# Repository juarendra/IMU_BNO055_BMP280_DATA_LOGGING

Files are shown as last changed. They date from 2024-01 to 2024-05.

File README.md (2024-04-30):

# IMU_BNO055_BMP280_DATA_LOGGING

## Spesification
- ESP32 WROOM
- USB TYPE C
- FT231 as USB Proggrammer
- BNO055
- BMP280
- OLED DISPLAY
- I2C expander for Button
- Modul charger tp4056 for Charger Lipo Batt
- Switch On OFF
- SD Card as save Data Loging

## Preview Hardware
<p align="center">

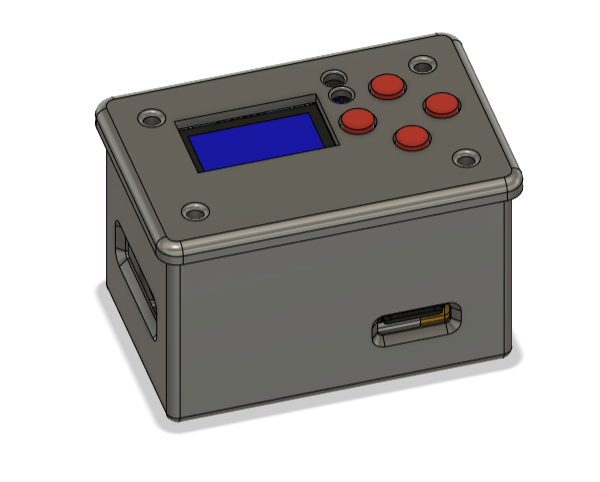
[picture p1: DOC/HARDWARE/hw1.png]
  
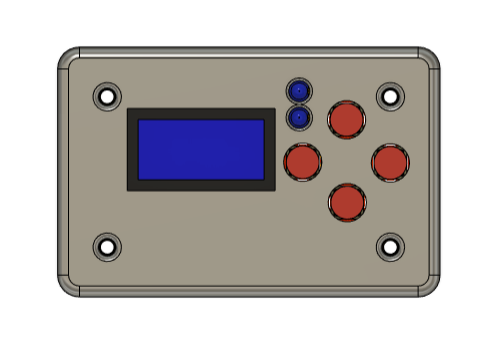
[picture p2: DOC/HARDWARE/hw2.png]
  
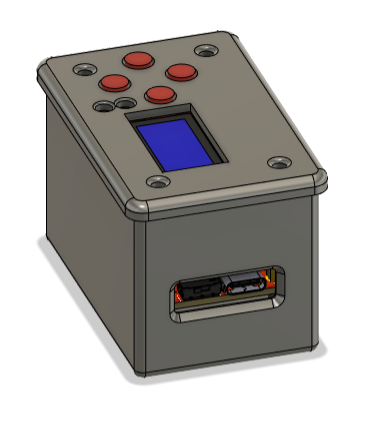
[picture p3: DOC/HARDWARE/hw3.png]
  
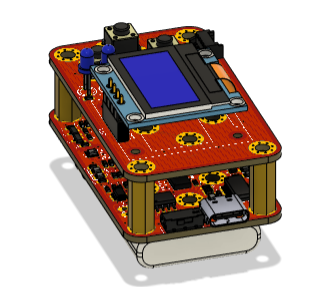
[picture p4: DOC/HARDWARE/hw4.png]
  
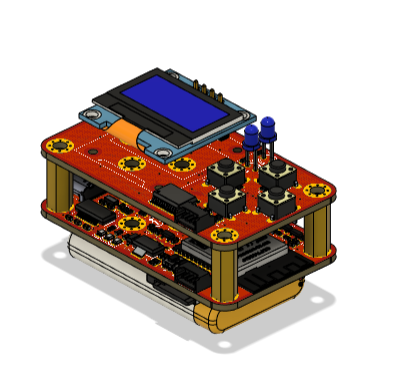
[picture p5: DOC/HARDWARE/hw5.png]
  
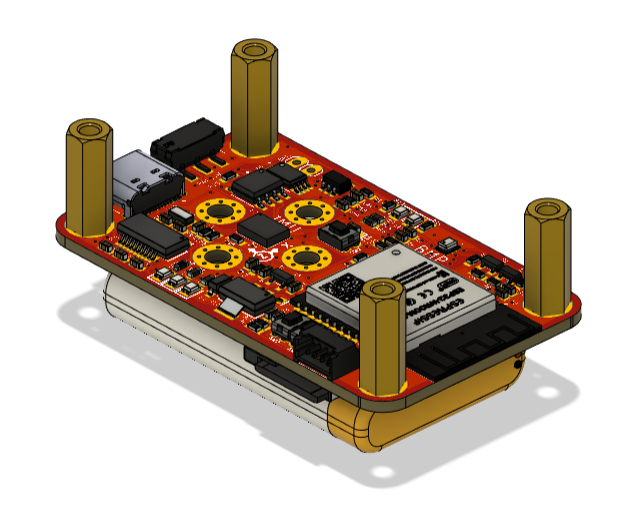
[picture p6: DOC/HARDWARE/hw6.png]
  
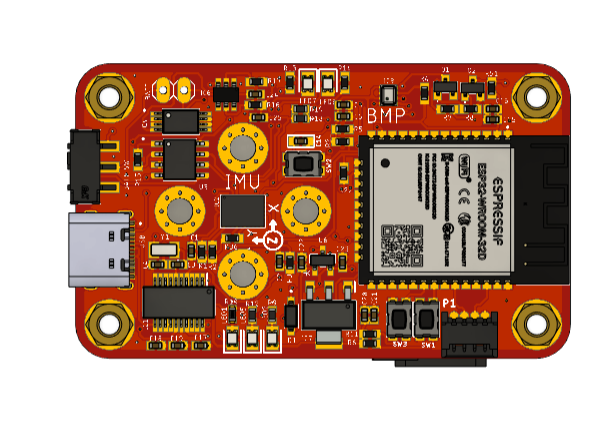
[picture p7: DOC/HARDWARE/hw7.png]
  
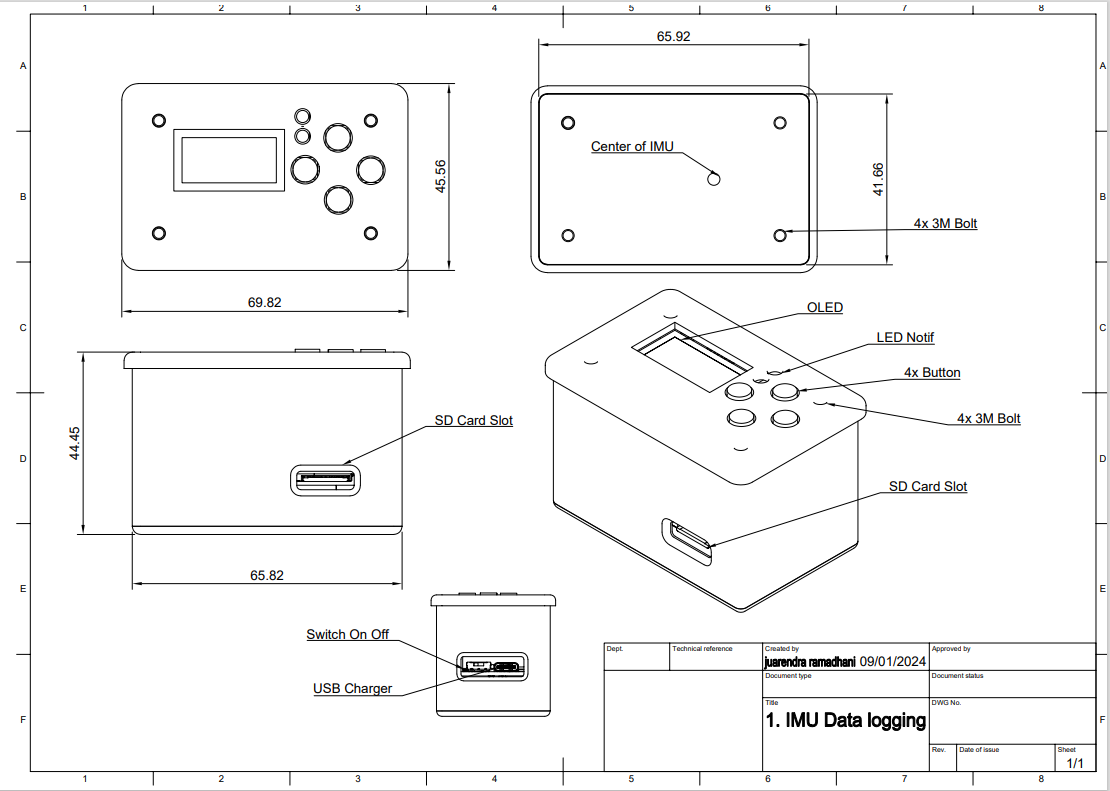
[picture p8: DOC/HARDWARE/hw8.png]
  

</p>

## USAGE 
- First you need to order or print the PCB based the gerber file on [this folder](https://github.com/juarendra/IMU_BNO055_BMP280_DATA_LOGGING/tree/main/GERBER)
- there are two PCB File, first is the MAIN Board and second is the UI with OLED and Button
- you need to print all PCB file to your favorite Manufacture PCB.
- then you can order all component based the BOM LIST file on [this folder](https://github.com/juarendra/IMU_BNO055_BMP280_DATA_LOGGING/tree/main/BOM).
- after All PCBs and All Component are receive, you can start the assembly 
- Then Print Case on [this Folder](https://github.com/juarendra/IMU_BNO055_BMP280_DATA_LOGGING/tree/main/CASE) with your 3D print

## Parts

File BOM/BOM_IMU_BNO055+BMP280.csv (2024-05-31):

Qty | Value | Device | Package | Parts | Description | AVAILABILITY | CHECK_PRICES | DESCRIPTION | DIGIKEY_PARTNUMBER | DIGIKEY_PRICE-STOCK | HEIGHT | LCSC_PART_NUMBER | LCSC_PRICE-STOCK | MANUFACTURER_NAME | MANUFACTURER_PART_NUMBER | MF | MOUSER_PART_NUMBER | MOUSER_PRICE-STOCK | MP | PACKAGE | PART_NUMBER | POPULARITY | PRICE | PURCHASE-URL | SNAPEDA_LINK | VALUE
1 |  | PINHD-1X2 | 1X02 | BATT | PIN HEADER |  |  |  |  |  |  |  |  |  |  |  |  |  |  |  |  | 98
7 | 0 | RC0603FR-070RL | RESC1608X55N | R29, R30, R31, R32, R33, R34, R35 | YAGEO - RC0603FR-070RL - Zero Ohm Resistor, Jumper, 0603 [1608 Metric], Thick Film, 100 mW, 1 A, Surface Mount Device |  |  | YAGEO - RC0603FR-070RL - Zero Ohm Resistor, Jumper, 0603 [1608 Metric], Thick Film, 100 mW, 1 A, Surface Mount Device |  |  | 0.55mm |  |  | YAGEO | RC0603FR-070RL |  | 603-RC0603FR-070RL | https://www.mouser.co.uk/ProductDetail/YAGEO/RC0603FR-070RL?qs=0yPvnVz5%2FmpDQv43TwvCfw%3D%3D
1 | 1.2k | ESR03EZPJ102 | RESC1608X55N | R15 | Thick Film Resistors - SMD 0603 1Kohm 5% Anti Surge AEC-Q200 |  |  | Thick Film Resistors - SMD 0603 1Kohm 5% Anti Surge AEC-Q200 | RHM1.0KDCT-ND | https://www.digikey.com/product-detail/en/rohm-semiconductor/ESR03EZPJ102/RHM1-0KDCT-ND/1762924 | 0.55mm |  |  | ROHM Semiconductor | ESR03EZPJ102 |  | 755-ESR03EZPJ102 | https://www.mouser.co.uk/ProductDetail/ROHM-Semiconductor/ESR03EZPJ102?qs=DyUWGjl%252BcVvjMuV%252BzioV7Q%3D%3D |  |  |  |  |  |  |  | 1k
1 | 100 | ESR03EZPJ102 | RESC1608X55N | R16 | Thick Film Resistors - SMD 0603 1Kohm 5% Anti Surge AEC-Q200 |  |  | Thick Film Resistors - SMD 0603 1Kohm 5% Anti Surge AEC-Q200 | RHM1.0KDCT-ND | https://www.digikey.com/product-detail/en/rohm-semiconductor/ESR03EZPJ102/RHM1-0KDCT-ND/1762924 | 0.55mm |  |  | ROHM Semiconductor | ESR03EZPJ102 |  | 755-ESR03EZPJ102 | https://www.mouser.co.uk/ProductDetail/ROHM-Semiconductor/ESR03EZPJ102?qs=DyUWGjl%252BcVvjMuV%252BzioV7Q%3D%3D |  |  |  |  |  |  |  | 1k
13 | 100nf | 885012206071 | CAPC1608X87N | C1, C2, C5, C6, C7, C8, C15, C17, C18, C19, C23, C24, C25 | Wurth Elektronik 0603 WCAP-CSGP 100nF Ceramic Multilayer Capacitor, 25 V dc, +125C, X7R Dielectric, +/-10% |  |  | Wurth Elektronik 0603 WCAP-CSGP 100nF Ceramic Multilayer Capacitor, 25 V dc, +125C, X7R Dielectric, +/-10% | 732-7989-1-ND | https://www.digikey.com/product-detail/en/w%C3%BCrth-elektronik/885012206071/732-7989-1-ND/5454616 | 0.87mm |  |  | Wurth Elektronik | 885012206071 |  | 710-885012206071 | https://www.mouser.co.uk/ProductDetail/Wurth-Elektronik/885012206071?qs=0KOYDY2FL2%2FEBQkuHgvarg%3D%3D |  |  |  |  |  |  |  | 100nf
20 | 10k | ESR03EZPJ103 | RESC1608X55N | R1, R2, R3, R4, R5, R6, R7, R8, R11, R20, R21, R22, R23, R24, R25, R26, R27, R28, R36, R51 | Thick Film Resistors - SMD 0603 10Kohm 5% Anti Surge AEC-Q200 |  |  | Thick Film Resistors - SMD 0603 10Kohm 5% Anti Surge AEC-Q200 | RHM10KDCT-ND | https://www.digikey.com/product-detail/en/rohm-semiconductor/ESR03EZPJ103/RHM10KDCT-ND/1762925 | 0.55mm |  |  | ROHM Semiconductor | ESR03EZPJ103 |  | 755-ESR03EZPJ103 | https://www.mouser.com/Search/Refine.aspx?Keyword=755-ESR03EZPJ103 |  |  |  |  |  |  |  | 10k
2 | 10nf | 885012206089 | CAPC1608X87N | C16, C21 | Wurth Elektronik 0603 WCAP-CSGP 10nF Ceramic Multilayer Capacitor, 50 V dc, +125C, X7R Dielectric, +/-10% |  |  | Wurth Elektronik 0603 WCAP-CSGP 10nF Ceramic Multilayer Capacitor, 50 V dc, +125C, X7R Dielectric, +/-10% | 732-8007-1-ND | https://www.digikey.com/product-detail/en/w%C3%BCrth-elektronik/885012206089/732-8007-1-ND/5454634 | 0.87mm |  |  | Wurth Elektronik | 885012206089 |  | 710-885012206089 | https://www.mouser.co.uk/ProductDetail/Wurth-Elektronik/885012206089?qs=0KOYDY2FL28GvSbKh319Tw%3D%3D |  |  |  |  |  |  |  | 10nf
1 | 1N5819HW-7 | 1N5819HW-7 | SOD3715X145N | D1 | 1N5819HW Series 40 V 1 A Surface Mount Schottky Barrier Rectifier - SOD-123 Check availability | In Stock | https://www.snapeda.com/parts/1N5819HW-7/Diodes+Inc./view-part/?ref=eda | Diode Schottky 40 V 1A Surface Mount SOD-123 |  |  |  |  |  |  |  | Diodes Inc. |  |  | 1N5819HW-7 | SOD-123 Fairchild Semiconductor |  |  | None | https://www.snapeda.com/api/url_track_click_mouser/?unipart_id=51510&manufacturer=Diodes Inc.&part_name=1N5819HW-7&search_term=1n5819 | https://www.snapeda.com/parts/1N5819HW-7/Diodes+Inc./view-part/?ref=snap
3 | 1k | ESR03EZPJ102 | RESC1608X55N | R13, R14, R17 | Thick Film Resistors - SMD 0603 1Kohm 5% Anti Surge AEC-Q200 |  |  | Thick Film Resistors - SMD 0603 1Kohm 5% Anti Surge AEC-Q200 | RHM1.0KDCT-ND | https://www.digikey.com/product-detail/en/rohm-semiconductor/ESR03EZPJ102/RHM1-0KDCT-ND/1762924 | 0.55mm |  |  | ROHM Semiconductor | ESR03EZPJ102 |  | 755-ESR03EZPJ102 | https://www.mouser.co.uk/ProductDetail/ROHM-Semiconductor/ESR03EZPJ102?qs=DyUWGjl%252BcVvjMuV%252BzioV7Q%3D%3D |  |  |  |  |  |  |  | 1k
1 | 1uF | CAP_CERAMIC0603 | 0603 | C14 | Ceramic Capacitors
2 | 1uf | 885012206071 | CAPC1608X87N | C20, C22 | Wurth Elektronik 0603 WCAP-CSGP 100nF Ceramic Multilayer Capacitor, 25 V dc, +125C, X7R Dielectric, +/-10% |  |  | Wurth Elektronik 0603 WCAP-CSGP 100nF Ceramic Multilayer Capacitor, 25 V dc, +125C, X7R Dielectric, +/-10% | 732-7989-1-ND | https://www.digikey.com/product-detail/en/w%C3%BCrth-elektronik/885012206071/732-7989-1-ND/5454616 | 0.87mm |  |  | Wurth Elektronik | 885012206071 |  | 710-885012206071 | https://www.mouser.co.uk/ProductDetail/Wurth-Elektronik/885012206071?qs=0KOYDY2FL2%2FEBQkuHgvarg%3D%3D |  |  |  |  |  |  |  | 100nf
2 | 22pf | 885012006004 | CAPC1608X87N | C3, C4 | Multilayer Ceramic Chip Capacitor WCAP-CSGP Series 0603 22pF NP00603220J010DFCT10000 |  |  | Multilayer Ceramic Chip Capacitor WCAP-CSGP Series 0603 22pF NP00603220J010DFCT10000 |  |  | 0.87mm |  |  | Wurth Elektronik | 885012006004 |  | 710-885012006004 | https://www.mouser.co.uk/ProductDetail/Wurth-Elektronik/885012006004?qs=0KOYDY2FL2%252BKoFRSQTlJcA%3D%3D |  |  |  |  |  |  |  | 22pf
3 | 330 | ERJ-H3EF3300V | ERJH3 | R9, R10, R12 | Power Rating 0.125W,Resistance 330 Ohm,LxW(EIA) 1.6 x 0.8 (EIA:0603) mm |  |  | Power Rating 0.125W,Resistance 330 Ohm,LxW(EIA) 1.6 x 0.8 (EIA:0603) mm |  |  | mm |  |  | Panasonic | ERJ-H3EF3300V |  | 667-ERJ-H3EF3300V | https://www.mouser.co.uk/ProductDetail/Panasonic/ERJ-H3EF3300V?qs=eP2BKZSCXI61roRLPi8W7w%3D%3D |  |  |  |  |  |  |  | 330
8 | 3MM_HOLE | 3MM_HOLE | 3MM_HOLE | H1, H2, H3, H4, H5, H6, H7, H8 | Cool looking 3mm hole with ground connection
1 | 40k2 | ERJ-S03F4022V | RESC1608X55N | R37 | Thick Film Resistors - SMD 0603 40.2Kohms 1% Anti-Sulfur |  |  | Thick Film Resistors - SMD 0603 40.2Kohms 1% Anti-Sulfur |  |  | 0.55mm |  |  | Panasonic | ERJ-S03F4022V |  | 667-ERJ-S03F4022V | https://www.mouser.com/Search/Refine.aspx?Keyword=667-ERJ-S03F4022V
2 | 47k | ERJ-H3EF3300V | ERJH3 | R18, R19 | Power Rating 0.125W,Resistance 330 Ohm,LxW(EIA) 1.6 x 0.8 (EIA:0603) mm |  |  | Power Rating 0.125W,Resistance 330 Ohm,LxW(EIA) 1.6 x 0.8 (EIA:0603) mm |  |  | mm |  |  | Panasonic | ERJ-H3EF3300V |  | 667-ERJ-H3EF3300V | https://www.mouser.co.uk/ProductDetail/Panasonic/ERJ-H3EF3300V?qs=eP2BKZSCXI61roRLPi8W7w%3D%3D |  |  |  |  |  |  |  | 330
1 | 53048-0410 | 53048-0410 | 53048-0410 | P1 | HEADER Check availability | In Stock | https://www.snapeda.com/parts/53048-0410/Molex/view-part/?ref=eda | 4 way through board PCB 90deg header | Molex Incorporated 53048-0410 |  |  |  |  |  |  |  | Molex |  |  | 53048-0410 | None |  |  | None |  | https://www.snapeda.com/parts/53048-0410/Molex/view-part/?ref=snap
1 | BMP280 | BMP280 | 8-PIN-METAL-LID-LGA | IC3 | Digital Pressure Sensor |  |  | Digital Pressure Sensor |  |  | mm |  |  | BOSCH | bmp280 |  | 262-BMP280 | https://www.mouser.co.uk/ProductDetail/Bosch-Sensortec/BMP280?qs=QhAb4EtQfbUP9Z%252BCHM3Wyg%3D%3D
1 | BN055 | 1658_BNO055 | LGA-28_3.80X5.20/0.5 | IC2 | BN055 Intelligent 9-axis absolute orientation sensor |  |  |  |  |  |  |  |  |  |  |  |  |  |  |  | BNO055 |  |  |  |  | BN055
1 | DW01A | DW01A | SOT23-6 | IC6 | Check availability | Not in stock | https://www.snapeda.com/parts/DW01A/Fortune+Semiconductor/view-part/?ref=eda | One Cell Lithium-ion/Polymer Battery Protection IC |  |  |  |  |  |  |  | Fortune Semiconductor |  |  | DW01A | SOT-23-6 Fortune Semiconductor |  |  | None |  | https://www.snapeda.com/parts/DW01A/Fortune+Semiconductor/view-part/?ref=snap
1 | ECS-.327-12.5-34B | ECS-.327-12.5-34B | ECX-31B | Y1 | Crystals 32.768KHz 20ppm 12.5pF -40C +85C |  |  | Crystals 32.768KHz 20ppm 12.5pF -40C +85C |  |  | mm |  |  | ECS | ECS-.327-12.5-34B |  | 520-ECS-327-12.5-34B | https://www.mouser.co.uk/ProductDetail/ECS/ECS-.327-12.5-34B?qs=muFWWzTLGEJ4ncukpyY8Bw%3D%3D
1 | ESP32-WROOM-32D | ESP32-WROOM-32D | MODULE_ESP32-WROOM-32D | U4 | Bluetooth, WiFi 802.11b/g/n, Bluetooth v4.2 + EDR, Class 1, 2 and 3 Transceiver Module 2.4GHz ~ 2.5GHz Integrated, Trace Surface Mount Check availability | In Stock |  | Bluetooth, WiFi 802.11b/g/n, Bluetooth v4.2 +EDR, Class 1, 2 and 3 Transceiver Module 2.4GHz ~ 2.5GHz Integrated |  |  |  |  |  |  |  | Espressif Systems |  |  | ESP32-WROOM-32D | Module Espressif Systems |  |  | None | https://pricing.snapeda.com/search/part/ESP32-WROOM-32D/?ref=eda
1 | FS8205A | FS8205A | SOP65P640X120-8N | Q4 | N/A Check availability | Not in stock | https://www.snapeda.com/parts/FS8205A/Fortune+Semiconductor/view-part/?ref=eda |  |  |  |  |  |  |  |  | Fortune Semiconductor |  |  | FS8205A | Package |  |  | None |  | https://www.snapeda.com/parts/FS8205A/Fortune+Semiconductor/view-part/?ref=snap
1 | FT231XS-R | FT231XS-R | SOP64P599X175-20N | IC1 | FTDI Chip FT231XS-R, Interface RS232, RS422, RS485, SIE, UART 3MBd, 5 V, 20-pin, SSOP |  |  | FTDI Chip FT231XS-R, Interface RS232, RS422, RS485, SIE, UART 3MBd, 5 V, 20-pin, SSOP |  |  | 1.753mm |  |  | FTDI Chip | FT231XS-R |  | 895-FT231XS-R | https://www.mouser.co.uk/ProductDetail/FTDI/FT231XS-R?qs=Gp1Yz1mis3WduRPsgrTbtg%3D%3D
5 | Green | 150080BS75000 | LEDC2012X80N | LED1, LED2, LED5, LED6, LED7 | LED,Wurth Elektronik,150080BS75000 Wurth Elektronik 150080BS75000, WL-SMCW Series Blue LED, 470 nm 2012 (0805) Clear, Rectangle Lens SMD package |  |  | LED,Wurth Elektronik,150080BS75000 Wurth Elektronik 150080BS75000, WL-SMCW Series Blue LED, 470 nm 2012 (0805) Clear, Rectangle Lens SMD package |  |  | 0.8mm |  |  | Wurth Elektronik | 150080BS75000 |  | 710-150080BS75000 | https://www.mouser.co.uk/ProductDetail/Wurth-Elektronik/150080BS75000?qs=2kOmHSv6VfT2tBo3UPVqAQ%3D%3D |  |  |  |  |  |  |  | Green
1 | JS102011SAQN | JS102011SAQN | SW_JS102011SAQN | BATT_SW | <b> | In Stock | https://www.snapeda.com/parts/JS102011SAQN/C%2526K/view-part/?ref=eda | Slide Switch SPDT Surface Mount, Right Angle |  |  |  |  |  |  |  | C&K |  |  | JS102011SAQN | None |  |  | None | https://pricing.snapeda.com/search?q=JS102011SAQN&ref=eda | https://www.snapeda.com/parts/JS102011SAQN/C%2526K/view-part/?ref=snap
3 | KMR2 | SWITCH_TACT_SMT4.6X2.8 | BTN_KMR2_4.6X2.8 | SW1, SW2, SW3 | SMT Tact Switches
1 | M3406-ADJ | M3406-ADJ | SOT95P280X100-5N | IC4 | Step-down type SOT-23-5 DC-DC Converters ROHS |  |  | Step-down type SOT-23-5 DC-DC Converters ROHS |  |  | 1mm | C83224 | https://www.lcsc.com/product-detail/DC-DC-Converters_XI-AN-Aerosemi-Tech-M3406-ADJ_C83224.html | XI'AN Aerosemi Tech | M3406-ADJ
1 | MICROSD-PUSH-OUT | MICROSD-PUSH-OUT | MICROSD-PUSH-OUT | U$3 | T-Flash Push-Out Micro SD Card Reader
1 | MLF2012A2R2KT000 | MLF2012A2R2KT000 | INDC2012X105N | L1 | 2.2 H Shielded Multilayer Inductor 50 mA 500mOhm Max 0805 (2012 Metric) |  |  | 2.2 H Shielded Multilayer Inductor 50 mA 500mOhm Max 0805 (2012 Metric) |  |  | 1.05mm |  |  | TDK | MLF2012A2R2KT000 |  | 810-MLF2012A2R2KT000 | https://www.mouser.co.uk/ProductDetail/TDK/MLF2012A2R2KT000?qs=pLY5GE0xrmL3Y2Jw%2FEGjFg%3D%3D
2 | MMBT3904-TP | MMBT3904-TP | SI2305TP | Q1, Q2 | Bipolar Transistors - BJT 40V |  |  | Bipolar Transistors - BJT 40V |  |  | mm |  |  | Micro Commercial Components (MCC) | MMBT3904-TP |  | 833-MMBT3904-TP | https://www.mouser.co.uk/ProductDetail/Micro-Commercial-Components-MCC/MMBT3904-TP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
1 | SI2301BDS-T1-E3 | SI2301BDS-T1-E3 | SOT95P237X112-3N | U6 | MOSFET Check availability | In Stock | https://www.snapeda.com/parts/SI2301BDS-T1-E3/Vishay+Siliconix/view-part/?ref=eda | MOSFET,P-Ch,VDSS -20V,RDS(ON) 0.08Ohm,ID -2.2A,TO-236 (SOT-23),PD 0.7W,VGS +/-8V | Siliconix / Vishay SI2301BDS-T1-E3 |  |  |  |  |  |  |  | Vishay |  |  | SI2301BDS-T1-E3 | SOT-23-3 Vishay Siliconix |  |  | None | https://www.snapeda.com/api/url_track_click_mouser/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 | https://www.snapeda.com/parts/SI2301BDS-T1-E3/Vishay+Siliconix/view-part/?ref=snap
1 | TP4056 | TP4056 | SOP127P600X175-9N | U3 | Complete single cell Li-Ion battery with a constant current / constant voltage linear charger Check availability | Not in stock | https://www.snapeda.com/parts/TP4056/NanJing+Top+Power+ASIC+Corp./view-part/?ref=eda | Complete single cell Li-Ion battery with a constant current / constant voltage linear charger |  |  |  |  |  |  |  | NanJing Top Power ASIC Corp. |  |  | TP4056 | Package |  |  | None |  | https://www.snapeda.com/parts/TP4056/NanJing+Top+Power+ASIC+Corp./view-part/?ref=snap
1 | TYPE-C-31-M-12 | TYPE-C-31-M-12 | HRO_TYPE-C-31-M-12 | USB | Check availability | Not in stock | https://www.snapeda.com/parts/TYPE-C-31-M-12/HRO+Electronics+Co.%252C+Ltd./view-part/?ref=eda | USB Connectors 24 Receptacle 1 8.94*7.3mm RoHS |  |  |  |  |  |  |  | HRO Electronics Co., Ltd. |  |  | TYPE-C-31-M-12 | Package |  |  | None |  | https://www.snapeda.com/parts/TYPE-C-31-M-12/HRO+Electronics+Co.%252C+Ltd./view-part/?ref=snap

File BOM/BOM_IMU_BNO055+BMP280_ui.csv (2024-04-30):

Qty | Value | Device | Package | Parts | Description | AVAILABILITY | CHECK_PRICES | DESCRIPTION | DIGIKEY_PARTNUMBER | DIGIKEY_PRICE-STOCK | HEIGHT | MANUFACTURER_NAME | MANUFACTURER_PART_NUMBER | MF | MOUSER_PART_NUMBER | MOUSER_PRICE-STOCK | MP | MPN | OC_FARNELL | OC_NEWARK | PACKAGE | POPULARITY | PRICE | SNAPEDA_LINK | VALUE
4 |  | 10-XX | B3F-10XX | S1, S2, S3, S4 | OMRON SWITCH |  |  |  |  |  |  |  |  |  |  |  |  | B3F-1000 | 176432 | 36M3542 |  | 72
2 |  | LED3MM | LED3MM | LED1, LED2 | LED |  |  |  |  |  |  |  |  |  |  |  |  |  |  |  |  | 97
2 | 100nf | 885012206071 | CAPC1608X87N | C1, C2 | Wurth Elektronik 0603 WCAP-CSGP 100nF Ceramic Multilayer Capacitor, 25 V dc, +125C, X7R Dielectric, +/-10% |  |  | Wurth Elektronik 0603 WCAP-CSGP 100nF Ceramic Multilayer Capacitor, 25 V dc, +125C, X7R Dielectric, +/-10% | 732-7989-1-ND | https://www.digikey.com/product-detail/en/w%C3%BCrth-elektronik/885012206071/732-7989-1-ND/5454616 | 0.87mm | Wurth Elektronik | 885012206071 |  | 710-885012206071 | https://www.mouser.co.uk/ProductDetail/Wurth-Elektronik/885012206071?qs=0KOYDY2FL2%2FEBQkuHgvarg%3D%3D |  |  |  |  |  |  |  |  | 100nf
6 | 10k | ESR03EZPJ103 | RESC1608X55N | R1, R2, R3, R4, R5, R6 | Thick Film Resistors - SMD 0603 10Kohm 5% Anti Surge AEC-Q200 |  |  | Thick Film Resistors - SMD 0603 10Kohm 5% Anti Surge AEC-Q200 | RHM10KDCT-ND | https://www.digikey.com/product-detail/en/rohm-semiconductor/ESR03EZPJ103/RHM10KDCT-ND/1762925 | 0.55mm | ROHM Semiconductor | ESR03EZPJ103 |  | 755-ESR03EZPJ103 | https://www.mouser.com/Search/Refine.aspx?Keyword=755-ESR03EZPJ103 |  |  |  |  |  |  |  |  | 10k
2 | 1k | ESR03EZPJ102 | RESC1608X55N | R7, R8 | Thick Film Resistors - SMD 0603 1Kohm 5% Anti Surge AEC-Q200 |  |  | Thick Film Resistors - SMD 0603 1Kohm 5% Anti Surge AEC-Q200 | RHM1.0KDCT-ND | https://www.digikey.com/product-detail/en/rohm-semiconductor/ESR03EZPJ102/RHM1-0KDCT-ND/1762924 | 0.55mm | ROHM Semiconductor | ESR03EZPJ102 |  | 755-ESR03EZPJ102 | https://www.mouser.co.uk/ProductDetail/ROHM-Semiconductor/ESR03EZPJ102?qs=DyUWGjl%252BcVvjMuV%252BzioV7Q%3D%3D |  |  |  |  |  |  |  |  | 1k
8 | 3MM_HOLE | 3MM_HOLE | 3MM_HOLE | H1, H2, H3, H4, H5, H6, H7, H8 | Cool looking 3mm hole with ground connection
1 | 53048-0410 | 53048-0410 | 53048-0410 | P1 | HEADER Check availability | In Stock | https://www.snapeda.com/parts/53048-0410/Molex/view-part/?ref=eda | 4 way through board PCB 90deg header | Molex Incorporated 53048-0410 |  |  |  |  |  | Molex |  |  | 53048-0410 |  |  |  | None |  | None | https://www.snapeda.com/parts/53048-0410/Molex/view-part/?ref=snap
1 | DISPLAY-OLED-128X64-I2C | DISPLAY-OLED-128X64-I2C | DISPLAY-OLED-128X64-I2C | U$1 | 128x64 Dot Matrix OLED Module based on SSD1306 chip
1 | PCF8575TS_1,118 | PCF8575TS_1,118 | SOP65P775X200-24N | IC1 | Interface - I/O Expanders |  |  | Interface - I/O Expanders |  |  | 2mm | NXP | PCF8575TS/1,118 |  | 771-PCF8575TSDB-T | https://www.mouser.co.uk/ProductDetail/NXP-Semiconductors/PCF8575TS-1118?qs=LOCUfHb8d9vMl26vh33NWQ%3D%3D

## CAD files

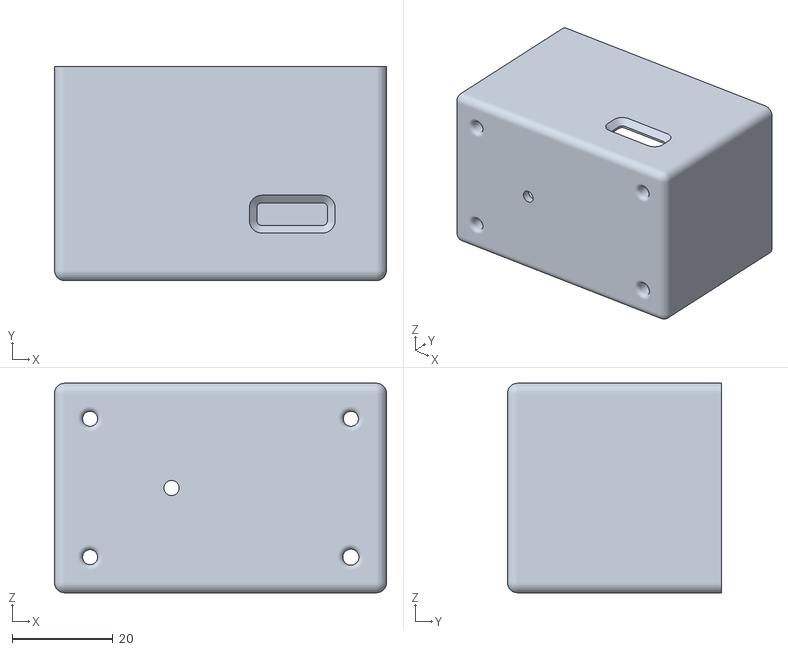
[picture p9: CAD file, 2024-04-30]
CASE/IMU_DATA_LOGGING_BOTTOM.stl
65.8 x 42.4 x 41.6

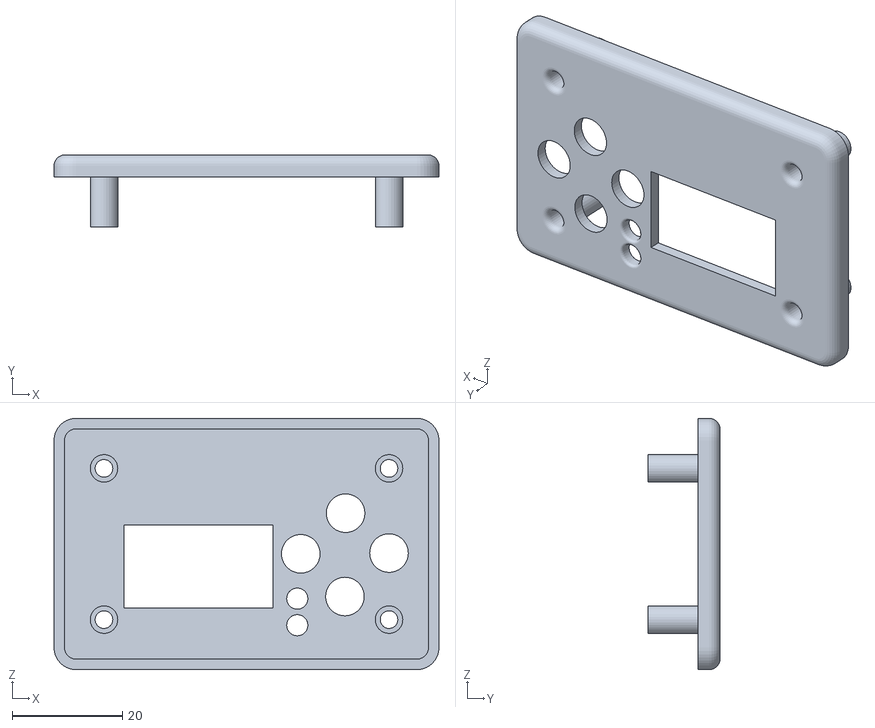
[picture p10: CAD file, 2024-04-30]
CASE/IMU_DATA_LOGGING_TOP.stl
69.8 x 13.1 x 45.6

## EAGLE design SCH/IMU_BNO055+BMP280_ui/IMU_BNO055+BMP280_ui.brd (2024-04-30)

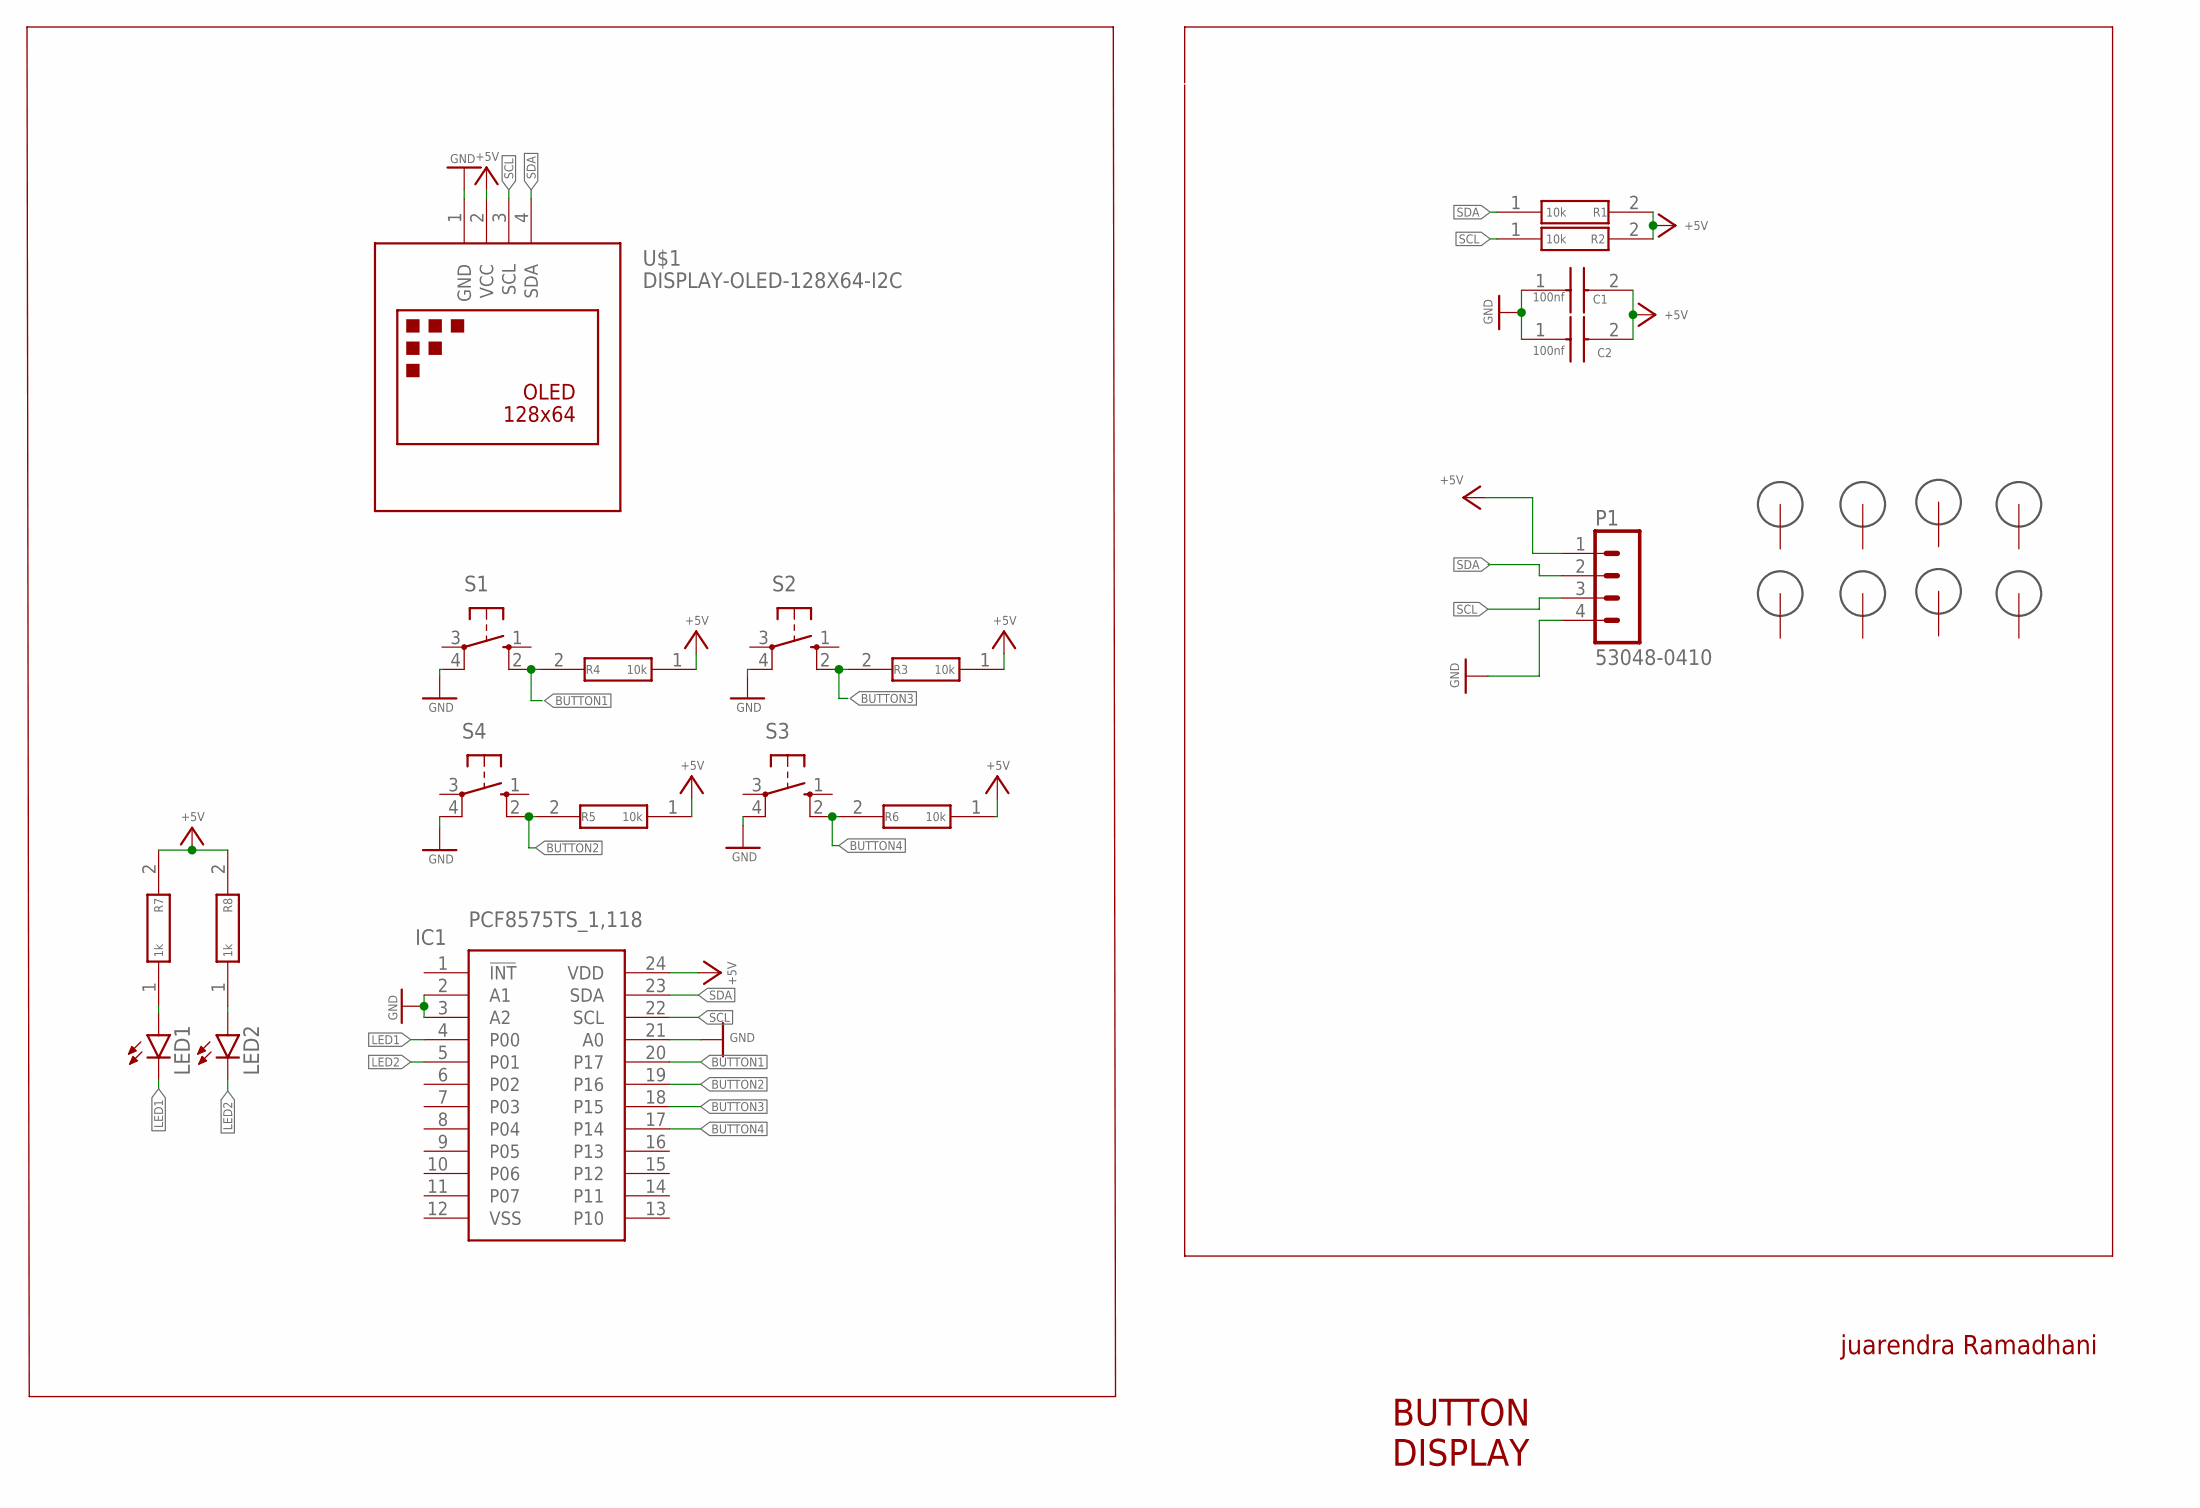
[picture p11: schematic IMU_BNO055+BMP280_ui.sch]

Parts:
C1, C2: 100nf; CAPC1608X87N
H1, H2, H3, H4, H5, H6, H7, H8: 3MM_HOLE
IC1: PCF8575TS_1,118; SOP65P775X200-24N
LED1, LED2: LED3MM
P1: 53048-0410
R1, R2, R3, R4, R5, R6: 10k; RESC1608X55N
R7, R8: 1k; RESC1608X55N
S1, S2, S3, S4: 10-XX; B3F-10XX
U$1: DISPLAY-OLED-128X64-I2C

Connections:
+5V: C1.2, C2.2, IC1.24 (VDD), P1.1, R1.2, R2.2, R3.1, R4.1, R5.1, R6.1, R7.2, R8.2, U$1.2 (VCC)
BUTTON1: IC1.20 (P17), R4.2, S1.2 (S1)
BUTTON2: IC1.19 (P16), R5.2, S4.2 (S1)
BUTTON3: IC1.18 (P15), R3.2, S2.2 (S1)
BUTTON4: IC1.17 (P14), R6.2, S3.2 (S1)
GND: C1.1, C2.1, IC1.2 (A1), IC1.3 (A2), IC1.21 (A0), P1.4, S1.4 (P1), S2.4 (P1), S3.4 (P1), S4.4 (P1), U$1.1 (GND)
LED1: IC1.4 (P00), LED1.K (C)
LED2: IC1.5 (P01), LED2.K (C)
unnamed: LED1.A, R7.1
unnamed: LED2.A, R8.1
SCL: IC1.22 (SCL), P1.3, R2.1, U$1.3 (SCL)
SDA: IC1.23 (SDA), P1.2, R1.1, U$1.4 (SDA)

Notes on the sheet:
BUTTON DISPLAY
juarendra Ramadhani

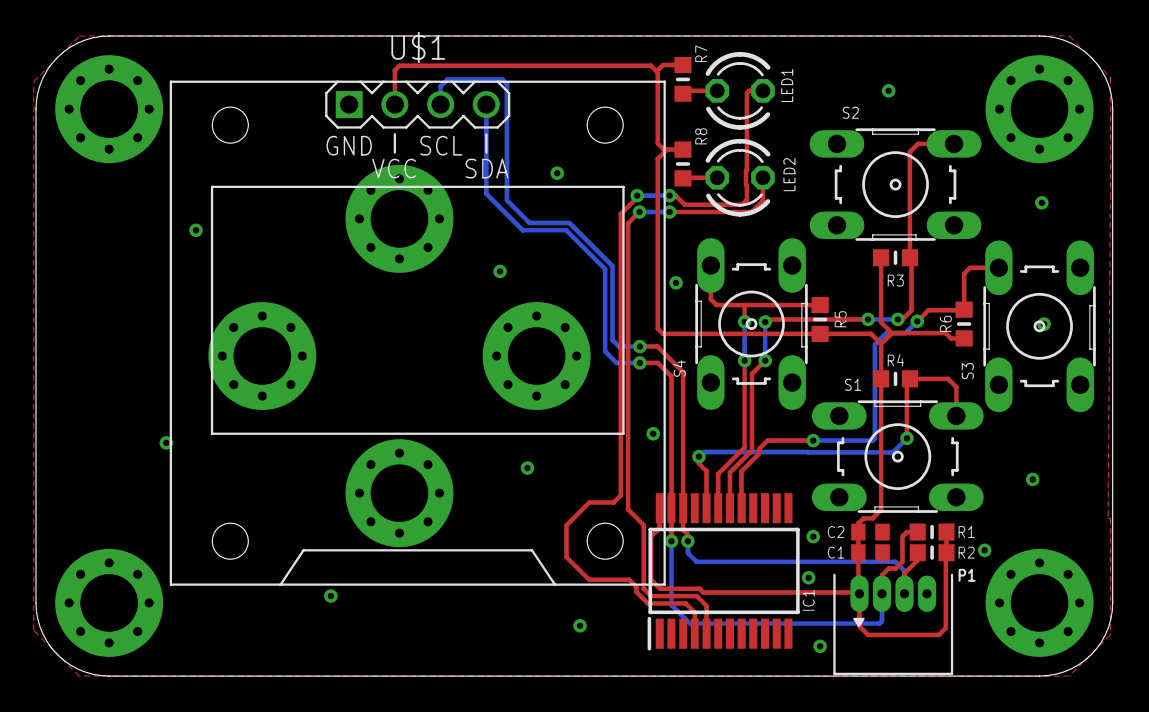
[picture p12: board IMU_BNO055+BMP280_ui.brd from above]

Board: 2 copper layers, 59.8 x 35.6 mm, 27 parts (0 on the bottom side), 12 nets.

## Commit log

2024-04-30 FEAT: add Schematic and Gerber File
    [IMU_BNO055+BMP280.brd, IMU_BNO055+BMP280.sch, IMU_BNO055+BMP280_ui.brd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]
2024-04-30 FEAT: add BOM :IST
    [BOM_IMU_BNO055+BMP280.csv, BOM_IMU_BNO055+BMP280_ui.csv]
2024-04-30 FEAT: Add Case
    [IMU_DATA_LOGGING_BOTTOM.stl, IMU_DATA_LOGGING_TOP.stl]
2024-05-31 FIX: fix ic stepdown to 3v3
    [copper_bottom.gbr, copper_top.gbr, drill_1_16.xln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]
2024-05-31 FIX: BOM LIST based from change ic stepdown
    [BOM_IMU_BNO055+BMP280.csv]

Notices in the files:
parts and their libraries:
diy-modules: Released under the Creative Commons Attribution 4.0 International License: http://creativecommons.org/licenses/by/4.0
